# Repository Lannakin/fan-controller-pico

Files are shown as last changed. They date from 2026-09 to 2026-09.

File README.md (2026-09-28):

<!-- ./README.md -->
# **Overview** - Fan Controller TXU0204 Pico
<!-- quick summary for github -->
⚠️⚠️⚠️ WARNING ⚠️⚠️⚠️

⚠️ i am just making this for a hobby.  i have no idea what i am doing.  i ⚠️
⚠️ am a cat.                                                              ⚠️

i hope github completely mangles my indentation.

using the gratuitously over-qualified raspberry pi pico series, this expansion
board is meant to control up to 4 fan connections that had better not exceed
1.5a. they should be 12vdc as well.

pwm output from pico is shifted from 3.3vdc to 5vdc because if i used a 12vdc
noctua fan, that's what noctua expects.

---

## **CREDITS FOR FONTS**

[WebPlus_ToshibaSat_8x14 and WebPlus_ToshibaSat_9x16 by VileR](https://**int10h**.org/oldschool-pc-fonts/)

[scientifica © 2020 Akshay Oppiliappan (nerdy@peppe.rs)](https://github.com/oppiliappan/scientifica)

## **Schematic Notes**
<!-- Key circuit blocks, design rationale -->
### expected fan needs gleaned from various documentation

power:
12vdc (less than 12.6vdc) power to fan  

pwm signal:
5vdc pullup, max 5.25vdc
should be open-collector
max current 5mA, but device should be capable of 8mA minimum
21 - 28kHz is the range for arctic's accepted quality control; 25kHz preferred

tach signal:
usually pulled up using 12vdc
noctua says max of 13v, but fan manufacturers probably only expect 5vdc
can be pulled up to 5vdc or 3.3vdc
probably open-collector
max current 5mA, but device should be capable of 8mA minimum
2 pulses per revolution

## **Layout Considerations**
<!-- Layer stackup, impedance, keep-outs -->
might be 2 layer
should really be 4 layer sign / gnd / pwr / sig
* oshpark

general routing
* every trace will "try" to return to ground using shortest possible path under?
  the trace
* try to avoid splitting ground planes, and use vias to help keep ground planes
  contiguous
* every time trace uses a via to switch layers, add via to ground as close as
  possible to give the voltage a return shorter path

signal routing:
* if having to cross another signal on another layer, try to do so
  perpendicularly
* try to keep the traces as spread out as possible
* larger traces have better noise rejection

## **Component Notes**
<!-- Click on designators like R1, C5, U3 to highlight on PCB -->
other signal translation component possibilities:
SN74LVC2G17
TXU0204 - integrated pull-down resistors
TXU0202 - integrated pull-down resistors

### TXU0204

"4-Bit Fixed Direction Voltage-Level Translator with Schmitt-Trigger Inputs and
3-State Outputs"

* vcc determines output voltage level
* using 2 to convert pico-output 3v3 pwm signals to 5v fan-input
* using 2 to convert fan-output 5v tachometer signals to 3v3 pico-input
* integrated 5Mohm pull-down resistors

## **Power Distribution**
<!-- Power rails, decoupling strategy -->
syntax of subsections:

```txt
### (heading size 3) Xvdc rail

device / component on the rail

* note about that device / component
* another note on the device / component
    * subnote on another note
    * another subnote on another note
* yet another note on that device / component
```

### general rail stuff

regarding rail traces / zones in general

* keep rail traces and zones off to the side as much as possible
* attempt to give them clear ground returns with gratuitous vias
* the zones for the positive inputs / outputs are mostly for heat sinking; the
  small size of the traces are plenty for these low voltages and amperages

### 12vdc rail

chanzon [2abn036f](https://www.amazon.com/dp/B07HNV6SBJ) 120vac 1a to 12vdc 3a wall wart:

* claims to be UL listed and shit but i highly doubt it is
* powers pico and this expansion board
* powers 4 x [P12 Pro PST](https://support.arctic.de/p12-pro-pst/docs) @ up to 0.3a each
* powers 1 x [OKI-78SR-5/1.5-W36-C](https://pim.murata.com/asset/pim4/nonIsolatedDCDCconverter/OKI-78SR_PDF_NONISOLATEDDCDCCONVERTER) @ 0.69a
* desired: transient, reverse polarity, and overcurrent protection; maybe also
  overvoltage and undervoltage
    * tvs diode: TPSMA6L12A, might be overkill
    * efuse choice 1: [TPS259482A](https://www.ti.com/lit/gpn/TPS25948)
    * efuse choice 2: [TPS259472A](https://www.ti.com/lit/ds/symlink/tps25947.pdf)
* may need filtering but i don't own a real oscilloscope soooooooooo

OKI-78SR-5/1.5-W36-C (12vdc input):

* based on [MP2467](https://www.monolithicpower.com/en/documentview/productdocument/index/version/2/document_type/Datasheet/lang/en/sku/MP2467/document_id/263/)
* recommends 2a fuse
* **inrush transient**: 0.16 A2-Sec.
* might need an electrolytic capacitor for up to 3ft of "20awg" wire from the
  wall wart to prevent instability or whatever
* no mention of needing input filtering;  that's very bold of you, murata
* the only filtering mentioned appears to be what is physically on the module's
  pcb: 2x 100uF (ceramic capacitors)

### 5vdc rail

OKI-78SR-5/1.5-W36-C (5vdc output):

* output of 5vdc at up to 1.5a
* mostly selected because it's in my drawer from years ago and has like <30mV
  ripple, which appears to be completely obscene even at like $6
* the okami series that this dcdc module is from has a cool wolf logo
* no mention of adding additional filtering; output filtering on the module pcb
  (assuming that's what "Cvbus" is) is 1x 1000uF (ceramic capacitor)

pico supplying via vsys

* [rec using p-mosfet](https://pip-assets.raspberrypi.com/categories/610-raspberry-pi-pico/documents/RP-008307-DS-2-pico-datasheet.pdf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) DMG2305UX for second source, or a schottky

### 3.3vdc rail

pico 5vdc to 3.3vdc converter (same for pico, w, 2, 2w): [RT6150](https://www.richtek.com/assets/product_file/RT6150A=RT6150B/DS6150AB-06.pdf)

* note that the datasheet won't fully cover the converter's output capabilities
  b/c the converter is the sum of the conversion circuit
* [super noisy in power save mode](https://pico-adc.markomo.me/PSU-Noise/) (115mV pk-pk vs 31mV); power efficiency is
  much worse, though
* maybe should use linear regulator
* if using analog, rec use external shunt ref like [lm4040](https://www.ti.com/lit/ds/symlink/lm4040.pdf) (in case using
  potentiometer for fan speed setting)
    * note: someone said for a human-operated potentiometer, the precision
      probably doesn't matter
* recommended: stay under 300mA

## **Signal Integrity**
<!-- Critical nets, routing constraints -->
this should probably be a 4-layer board, i don't think i can avoid splitting the
ground plane.

## **References**
<!-- Datasheets, application notes, calculations -->
### pcb production

oshpark:
  [oshpark - 2 layer prototype service](https://docs.oshpark.com/services/two-layer/)
  [oshpark - after dark (also 2 layer) service](https://docs.oshpark.com/services/afterdark/)
  [oshpark - 4 layer prototype service](https://docs.oshpark.com/services/four-layer/)

digikey:
  [pcb builder - faq](https://www.digikey.com/en/resources/design-tools/pcb-faqs)
  [pcb builder - technical specs](https://www.digikey.com/en/resources/design-tools/pcb-builder-technical-specs)

### efuses

[texas instruments "basics of efuses"](https://www.ti.com/lit/an/slva862a/slva862a.pdf)

### general 12vdc pwm fan control (pc fans)

[intel corporation "4-wire pulse width modulation (pwm) controlled fans"](https://glkinst.com/cables/cable_pics/4_Wire_PWM_Spec.pdf)
  reference to pulling up to 12v power to fans on tachometer pin

[edn article "4 wire pc fan"](https://www.edn.com/4-wire-pc-fan/)
[yoinked motherboard schematic picture from edn article](https://www.edn.com/wp-content/uploads/2019/12/2-Fan-Connector-Scheme.png)
  pulls up to 12v power to fans on tachometer pin

[texas instruments "fan controller overview"](https://www.ti.com/lit/po/sprt839/sprt839.pdf)
  "The tachometer output from the fan is
  typically an open-collector (or open-drain) output that requires a pull-up
  resistor. It's customary to connect this pull-up to the same voltage as the fan
  power."
  "you can still pull up to a lower voltage though" (slight paraphrasing)

### arctic p12 pro pst (ln)

[pwm curve for p12 pro pst series](https://support.arctic.de/products/p12-pro-pst/techdocs/P12%20Pro%20Series_PWMcurve.pdf)
[p12 pro pst docs page](https://support.arctic.de/p12-pro-pst/docs)
[p12 pro pst pwm guidelines](https://support.arctic.de/p12-pro-pst#toc-103)
[p12 pro pst ln docs page](https://support.arctic.de/p12-pro-pst-ln/docs)
[p12 pst pro ln pwm guidelines](https://support.arctic.de/p12-pro-pst-ln#toc-107)

### noctua fan jumpscare

[noctua "noctua pwm specifications white paper"](https://cdn.noctua.at/preview/media/Noctua_PWM_specifications_white_paper.pdf) Vtachometer for 12V fans: 5V
  recommended (13V max.)" at <5mA for 12v fans

### raspberry pi pico boards

[pico power supply](https://pip-assets.raspberrypi.com/categories/610-raspberry-pi-pico/documents/RP-008307-DS-2-pico-datasheet.pdf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)
  note: this applies to pico, pico w, pico 2, pico 2w

---

### layout filched from [KiNotes](https://pcbtools.xyz/tools/kinotes)

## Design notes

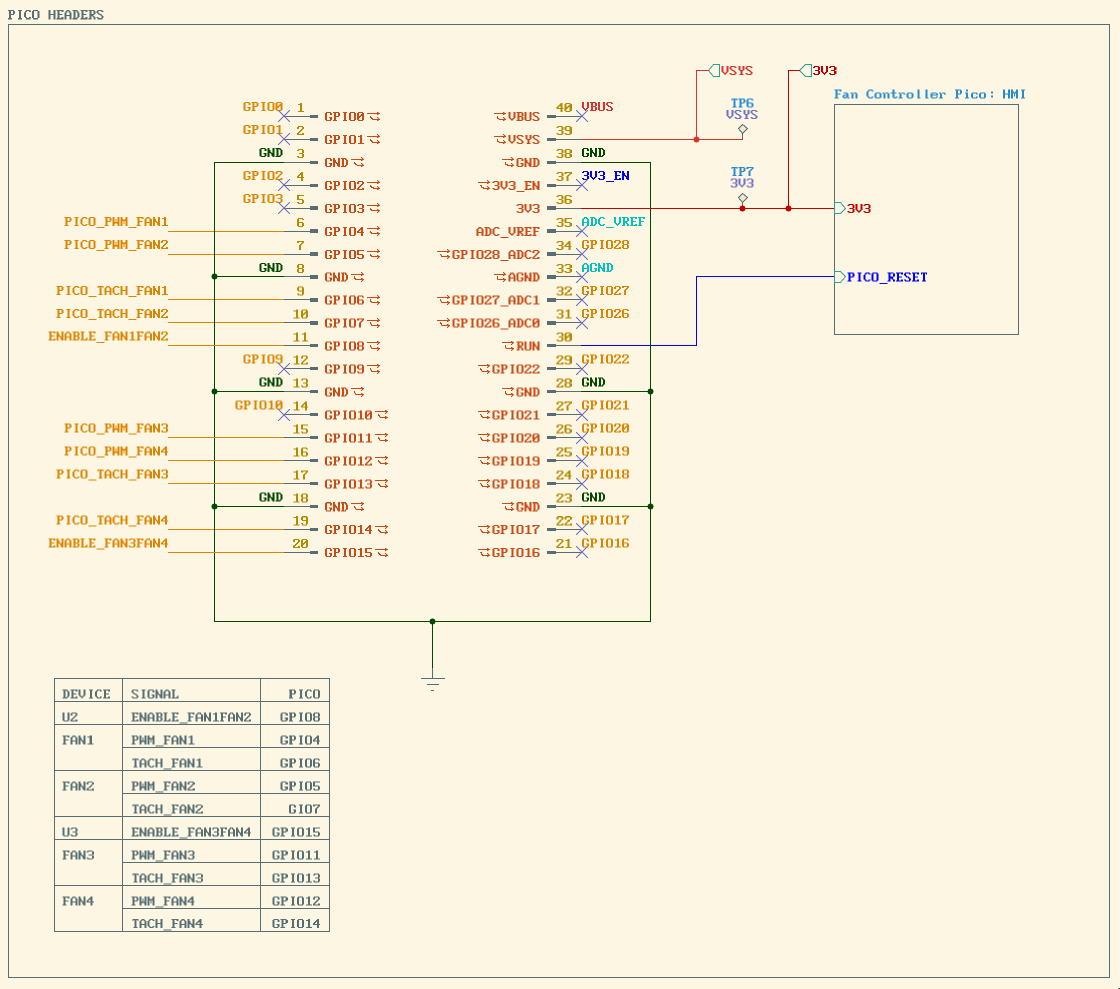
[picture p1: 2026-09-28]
misc/img/schematic_pico-headers.png

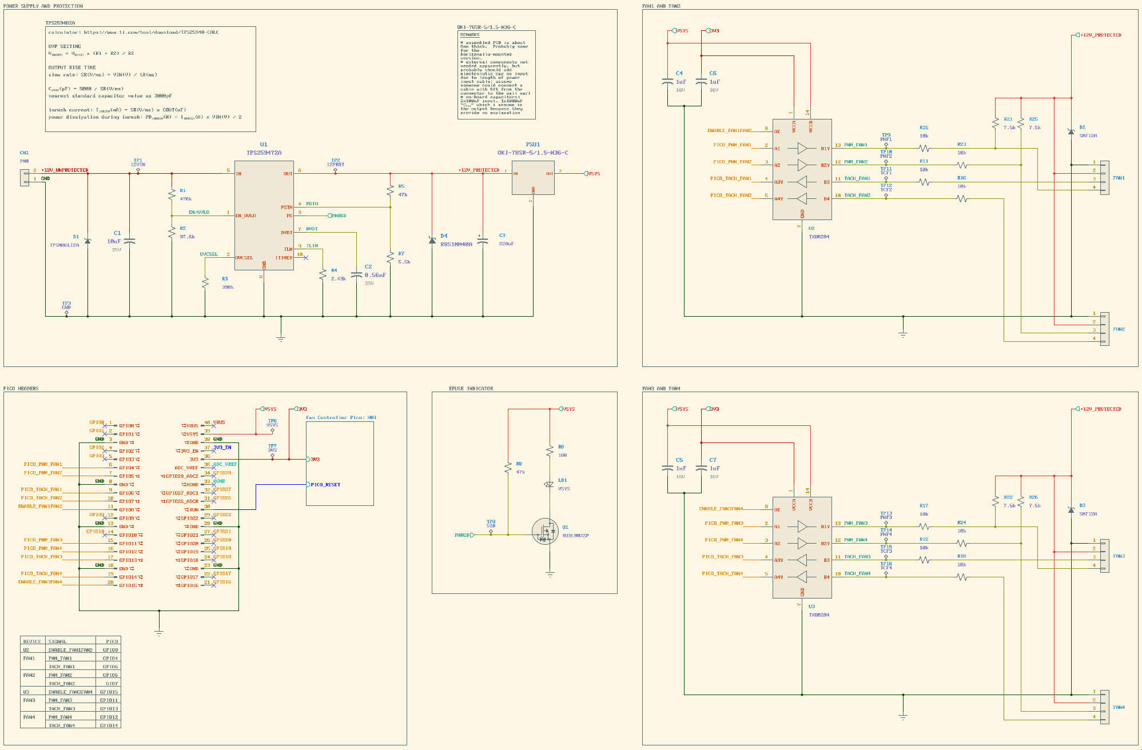
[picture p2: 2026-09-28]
misc/img/schematic_overview.png

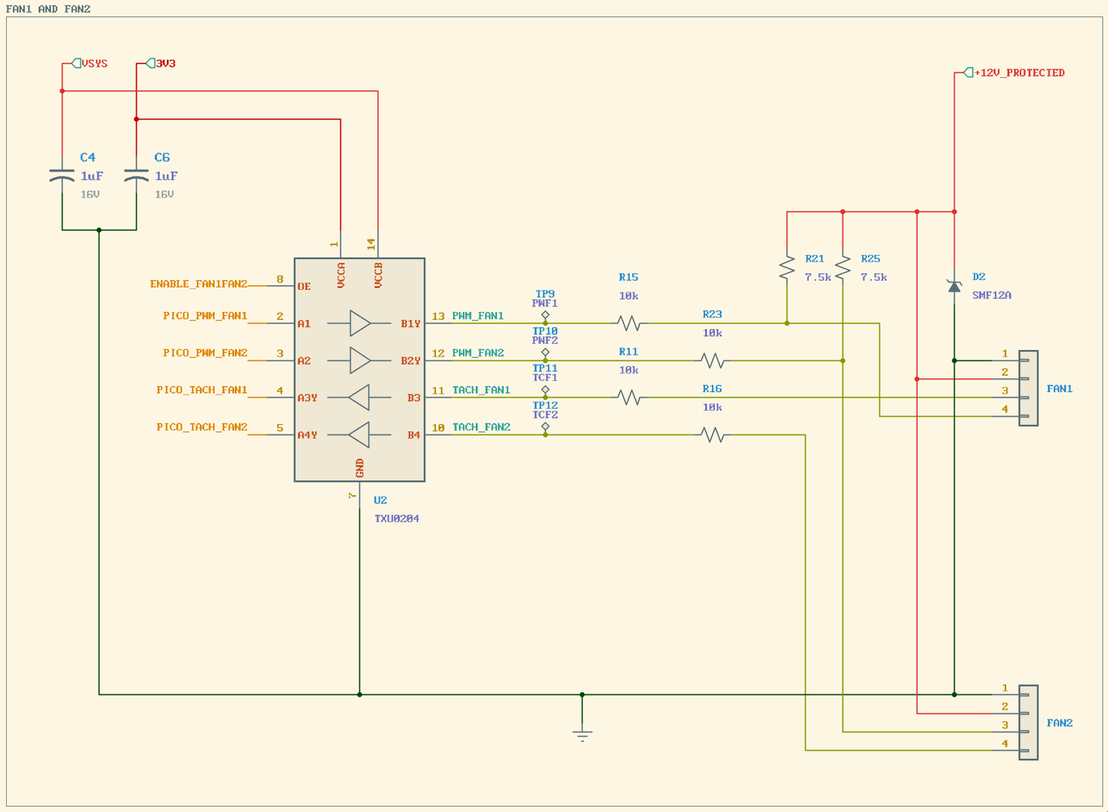
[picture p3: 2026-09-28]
misc/img/schematic_fan1-fan2.png

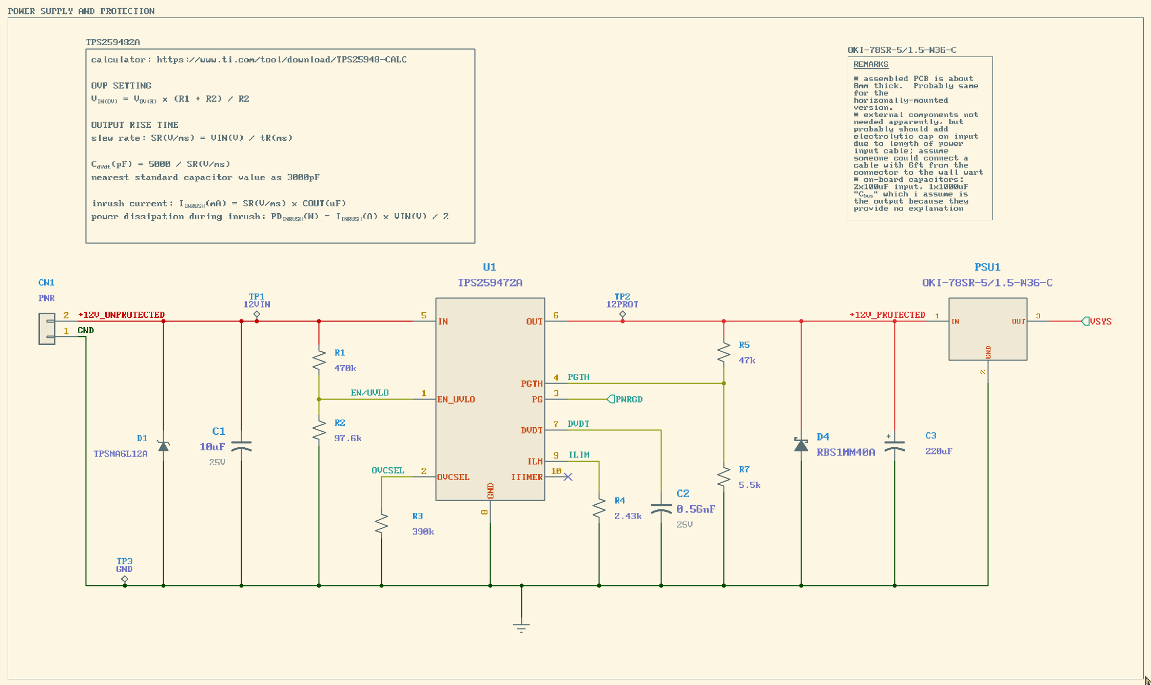
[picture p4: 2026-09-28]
misc/img/schematic_power-supply-protection.png

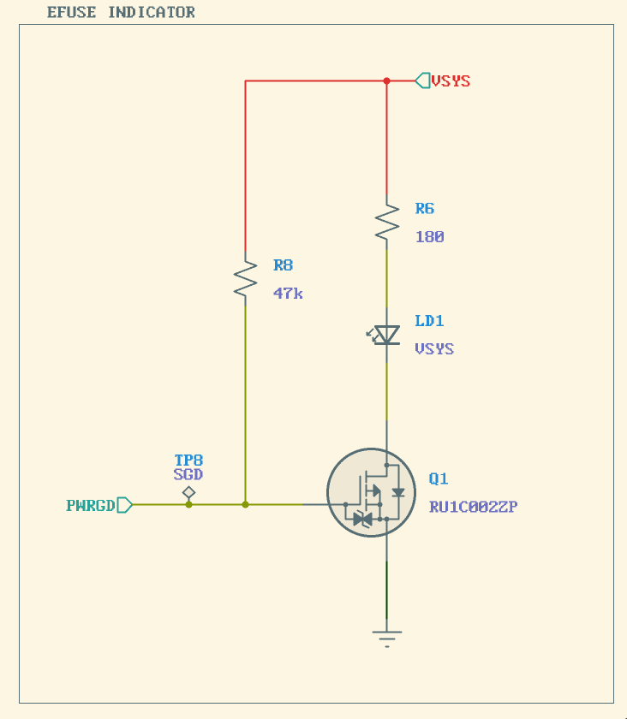
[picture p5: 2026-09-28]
misc/img/schematic_power-good-indicator.png

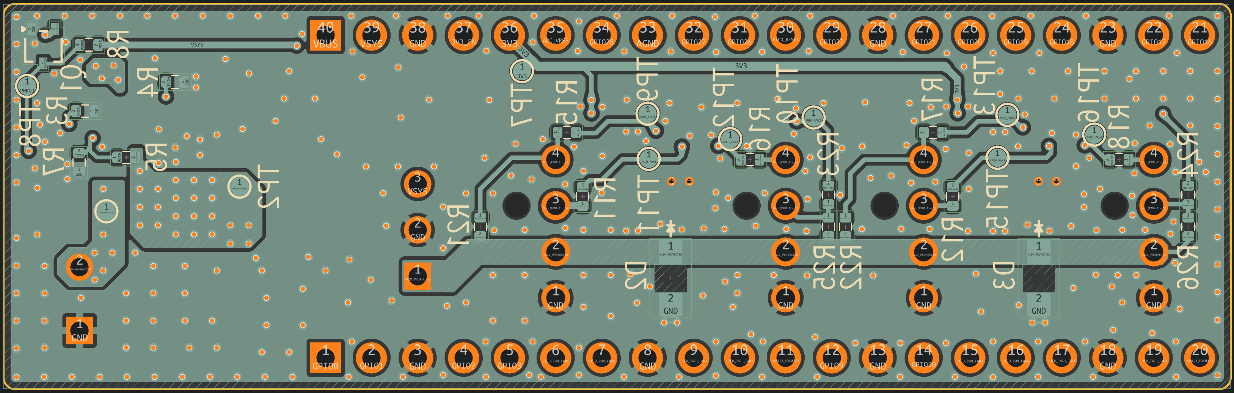
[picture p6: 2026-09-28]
misc/img/2d-b-cu.png

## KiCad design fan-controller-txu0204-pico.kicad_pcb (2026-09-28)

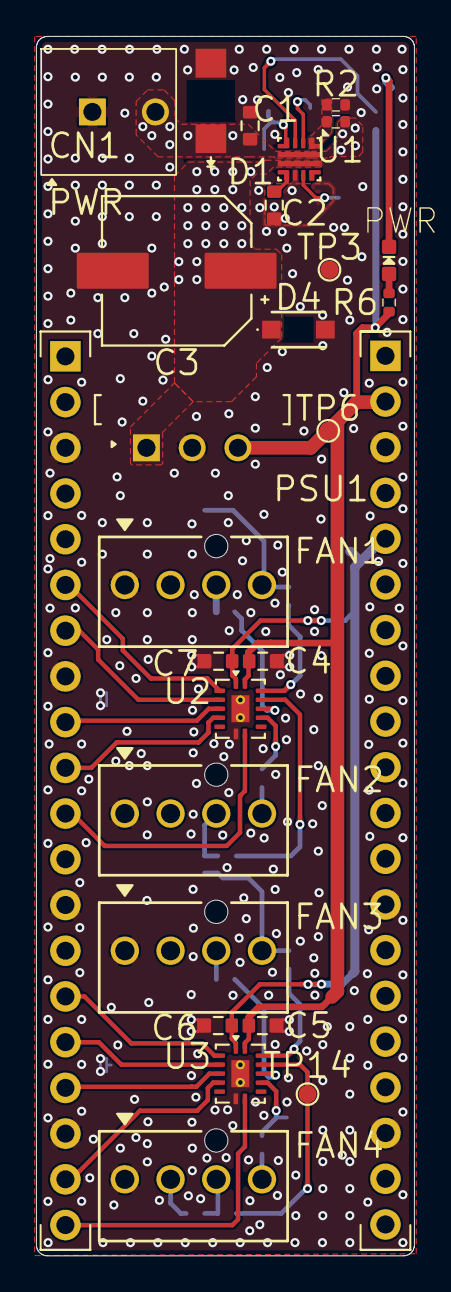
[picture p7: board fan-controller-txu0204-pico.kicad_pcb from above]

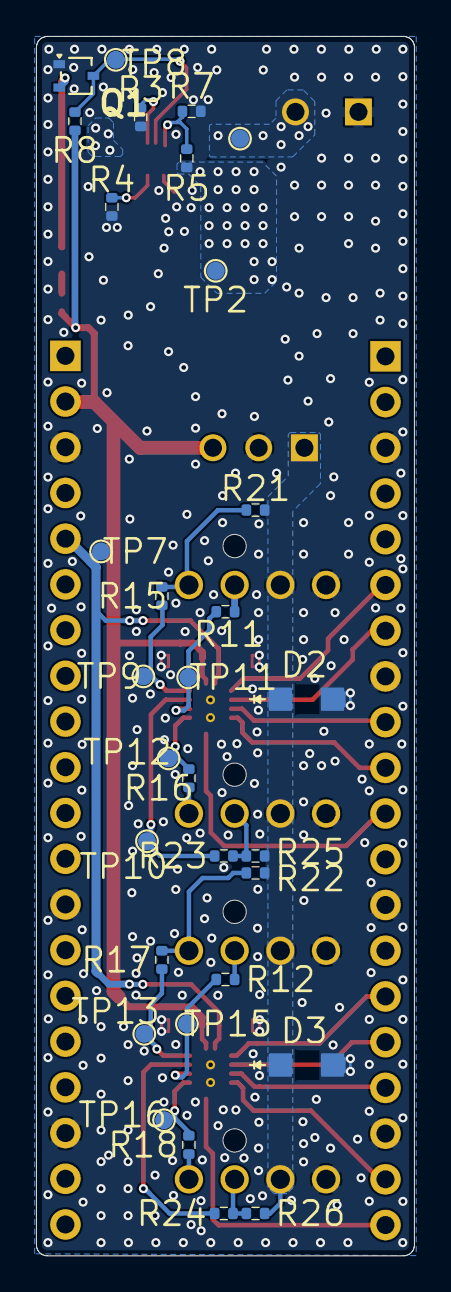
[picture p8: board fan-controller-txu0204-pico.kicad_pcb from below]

Board: 2 copper layers, 21.0 x 67.7 mm, 58 parts (31 on the bottom side), 39 nets.

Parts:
C1: 10uF; C_GRM18_0603_1608Metric_MURATA
C2: 0.56nF; C_GRM18_0603_1608Metric_MURATA
C3: 220uF; CAP_EEE-FT-SIZE-CODE-F_8x10_PANASONIC
C4, C5, C6, C7: 1uF; C_GRM18_0603_1608Metric_MURATA
CN1: PWR; 2-POS_FK-MPT_1891069_PHOENIX
CN2: RaspberryPi_Pico; RPI_Pico-CN_Left
CN3: RaspberryPi_Pico; RPI_Pico-CN_Right
D1: TPSMA6L12A; DIO_DO221AC_TPSMA6LSeries_LTF
D2, D3: SMF12A; D_SOD-123F_EATON
D4: RBS1MM40A; CR_RBS1MM_ROM
FAN1, FAN2, FAN3, FAN4: Conn_01x04; 470531000_4-POS-MALE-HEADER-VERTICAL_FAN_MOLEX
LD1: VSYS; LED_599-00XX-137F_0603_1608Metric
PSU1: OKI-78SR-5/1.5-W36-C; CONV_OKI-78SR-W36-C_MURATA2
Q1: RU1C002ZP; SOT-323T-3_SOT-323FL_SC-85
R1: 470k; R_RK37H_0402_1005Metric_KOA
R2: 97.6k; R_RK37H_0402_1005Metric_KOA
R3: 390k; R_RK37H_0402_1005Metric_KOA
R4: 2.43k; R_RK37H_0402_1005Metric_KOA
R5, R8: 47k; R_RK37H_0402_1005Metric_KOA
R6: 180; R_RK37H_0402_1005Metric_KOA
R7: 5.5k; R_RK37H_0402_1005Metric_KOA
R11, R12, R15, R16, R17, R18, R23, R24: 10k; R_RK37H_0402_1005Metric_KOA
R21, R22, R25, R26: 7.5k; R_RK37H_0402_1005Metric_KOA
TP1: 12VIN; TestPoint_Pad_D1.0mm
TP2: 12PROT; TestPoint_Pad_D1.0mm
TP3: GND; TestPoint_Pad_D1.0mm
TP6: VSYS; TestPoint_Pad_D1.0mm
TP7: 3V3; TestPoint_Pad_D1.0mm
TP8: SGD; TestPoint_Pad_D1.0mm
TP9: PWF1; TestPoint_Pad_D1.0mm
TP10: PWF2; TestPoint_Pad_D1.0mm
TP11: TCF1; TestPoint_Pad_D1.0mm
TP12: TCF2; TestPoint_Pad_D1.0mm
TP13: PWF3; TestPoint_Pad_D1.0mm
TP14: PWF4; TestPoint_Pad_D1.0mm
TP15: TCF3; TestPoint_Pad_D1.0mm
TP16: TCF4; TestPoint_Pad_D1.0mm
U1: TPS259472A; VFQFN10_RPW0010A_TI
U2, U3: TXU0204; DHWQFN-14-1EP_2.5x3mm_P0.5mm_EP1x1.5mm_ThermalVias

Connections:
/3V3: C6.1, C7.1, CN3.36 (3V3), TP7.1 (1_1), U2.1 (VCCA), U3.1 (VCCA)
/+12V_PROTECTED: C3.1, D2.1 (K), D3.1 (K), D4.1, FAN1.2, FAN2.2, FAN3.2, FAN4.2, PSU1.1 (IN), R5.2, R21.2, R22.2, R25.2, R26.2, TP2.1 (1_1), U1.6 (OUT)
/+12V_UNPROTECTED: C1.1, CN1.2 (+12VDC), D1.1 (K), R1.2, TP1.1 (1_1), U1.5 (IN)
/DVDT: C2.1, U1.7 (DVDT)
/ENABLE_FAN1FAN2: CN2.11 (GPIO8), U2.8 (OE)
/ENABLE_FAN3FAN4: CN2.20 (GPIO15), U3.8 (OE)
/EN/UVLO: R1.1, R2.2, U1.1 (EN_UVLO)
/ILIM: R4.2, U1.9 (ILM)
/OVCSEL: R3.2, U1.2 (OVCSEL)
/PGTH: R5.1, R7.2, U1.4 (PGTH)
/PICO_PWM_FAN1: CN2.6 (GPIO4), U2.2 (A1)
/PICO_PWM_FAN2: CN2.7 (GPIO5), U2.3 (A2)
/PICO_PWM_FAN3: CN2.15 (GPIO11), U3.2 (A1)
/PICO_PWM_FAN4: CN2.16 (GPIO12), U3.3 (A2)
/PICO_TACH_FAN1: CN2.9 (GPIO6), U2.4 (A3Y)
/PICO_TACH_FAN2: CN2.10 (GPIO7), U2.5 (A4Y)
/PICO_TACH_FAN3: CN2.17 (GPIO13), U3.4 (A3Y)
/PICO_TACH_FAN4: CN2.19 (GPIO14), U3.5 (A4Y)
/PWM_FAN1: R15.2, TP9.1 (1_1), U2.13 (B1Y)
/PWM_FAN2: R23.2, TP10.1 (1_1), U2.12 (B2Y)
/PWM_FAN3: R17.2, TP13.1 (1_1), U3.13 (B1Y)
/PWM_FAN4: R24.2, TP14.1 (1_1), U3.12 (B2Y)
/PWRGD: Q1.3 (GATE), R8.1, TP8.1 (1_1), U1.3 (PG)
/TACH_FAN1: R11.2, TP11.1 (1_1), U2.11 (B3)
/TACH_FAN2: R16.2, TP12.1 (1_1), U2.10 (B4)
/TACH_FAN3: R12.2, TP15.1 (1_1), U3.11 (B3)
/TACH_FAN4: R18.2, TP16.1 (1_1), U3.10 (B4)
/VSYS: C4.1, C5.1, CN3.39 (VSYS), PSU1.3 (OUT), R6.2, R8.2, TP6.1 (1_1), U2.14 (VCCB), U3.14 (VCCB)
GND: C1.2, C2.2, C3.2, C4.2, C5.2, C6.2, C7.2, CN1.1 (GND), CN2.3 (GND), CN2.8 (GND), CN2.13 (GND), CN2.18 (GND), CN3.23 (GND), CN3.28 (GND), CN3.38 (GND), D1.2 (A), D2.2 (A), D3.2 (A), D4.2, FAN1.1, FAN2.1, FAN3.1, FAN4.1, PSU1.2 (GND), Q1.1 (SOURCE), R2.1, R3.1, R4.1, R7.1, TP3.1 (1_1), U1.8 (GND), U2.7 (GND), U2.15 (PAD), U3.7 (GND), U3.15 (PAD)
unnamed: FAN1.3, R11.1
unnamed: FAN1.4, R15.1, R21.1
unnamed: FAN2.3, R23.1, R25.1
unnamed: FAN2.4, R16.1
unnamed: FAN3.3, R12.1
unnamed: FAN3.4, R17.1, R22.1
unnamed: FAN4.3, R24.1, R26.1
unnamed: FAN4.4, R18.1
unnamed: LD1.2 (A), R6.1
unnamed: LD1.1 (K), Q1.2 (DRAIN)

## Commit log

2026-09-28 tl;dr: initial commit
    =======================================================================
    added:
    ./
    LICENSE
    README.md
    fan-controller-pico_hmi.kicad_sch - aux board for operator
    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
    [fan-controller-pico_hmi.kicad_sch, fan-controller-txu0204-pico.kicad_pcb, fan-controller-txu0204-pico.kicad_sch]
2026-09-28 tl;dr: added and restructured license stuff
    licenses/ - appropriate licenses and notices
    curie-LICENSE.txt
    curie-NOTICE.txt
    fan-controller-pico-NOTICE.txt
    scientifica-LICENSE.txt
    scientifica-NOTICE.txt
    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
2026-10-11 tl;dr: switched to 4-layer pcb, overhauled 12vdc rail and protections, added 5vdc ORing ======================================================================== added: ./ .gitignore - ignore lockfile
    ------------------------------------------------------------------------
    removed:
    licenses/ - switched fonts to all WebPlus_ToshibaSat_8x14 and 9x16
    ------------------------------------------------------------------------
    modified:
    README.md - updated to reflect changes in design
    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
2026-10-13 tl;dr: update images, adjust rules, clean up notes, move 12v rail to power plane, adj signal traces
    misc/img/ - switch to 4-layer design from 2-layer
    2d-in1-cu.png
    2d-in2-cu.png
    -----------------------------------------------------------------------
    ./ - adjusted rules, cleaned up signal trace routing
    fan-controller-txu0204-pico.kicad_dru
    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
2026-10-15 tl;dr: re-added TVS protections to pwm and tach signals at fan connectors, rerouted 12v
    ========================================================================
    misc/img/ - improved images for pcb etc
    fan-controller-txu0204-pico.svg
    fan-controller-txu0204-pico__Assembly.pdf
    fan-controller-txu0204-pico_color-b.svg
    fan-controller-txu0204-pico_color-f.svg
    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
